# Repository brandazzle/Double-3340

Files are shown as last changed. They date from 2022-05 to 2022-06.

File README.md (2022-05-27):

# Dual 3340 VCO
This module implements two CEM3340/AS3340 VCO ICs, with front panel pulse width and coarse and fine pitch controls, and linear FM, 1V/octave, switchable hard sync (positive/negative/both), and attenuated PWM inputs.
The 1V/octave inputs are connected to each other via switching jacks, so you can control the pitch of the oscillators simultaneously. (Will need to test for pitch slackening with this.) 
\[This functionality can be customized by soldering only one of the 1V/oct input jacks' switch pins, or removed by soldering neither.\]
All outputs are re-centered and normalized to ±5V. A waveshaping circuit based on [Thomas Henry's VCO-1](https://www.birthofasynth.com/Thomas_Henry/Pages/VCO-1.html) provides a sine output. 
The switchable hard sync uses the hard-sync diode circuit from [the original Curtis Electromusic datasheet.](https://www.curtiselectromusic.com/family-law.html)
The module also implements the chip-to-chip soft synchronization described in the original datasheet, wth front-panel switches for each oscillator. Turning on the switch corresponding to each oscillator causes that oscillator to be synchronized by the other, so you can select sync either way, no sync, or mutual sync.

## Construction
<details><summary>View build instructions</summary>

</details>

## Calibration

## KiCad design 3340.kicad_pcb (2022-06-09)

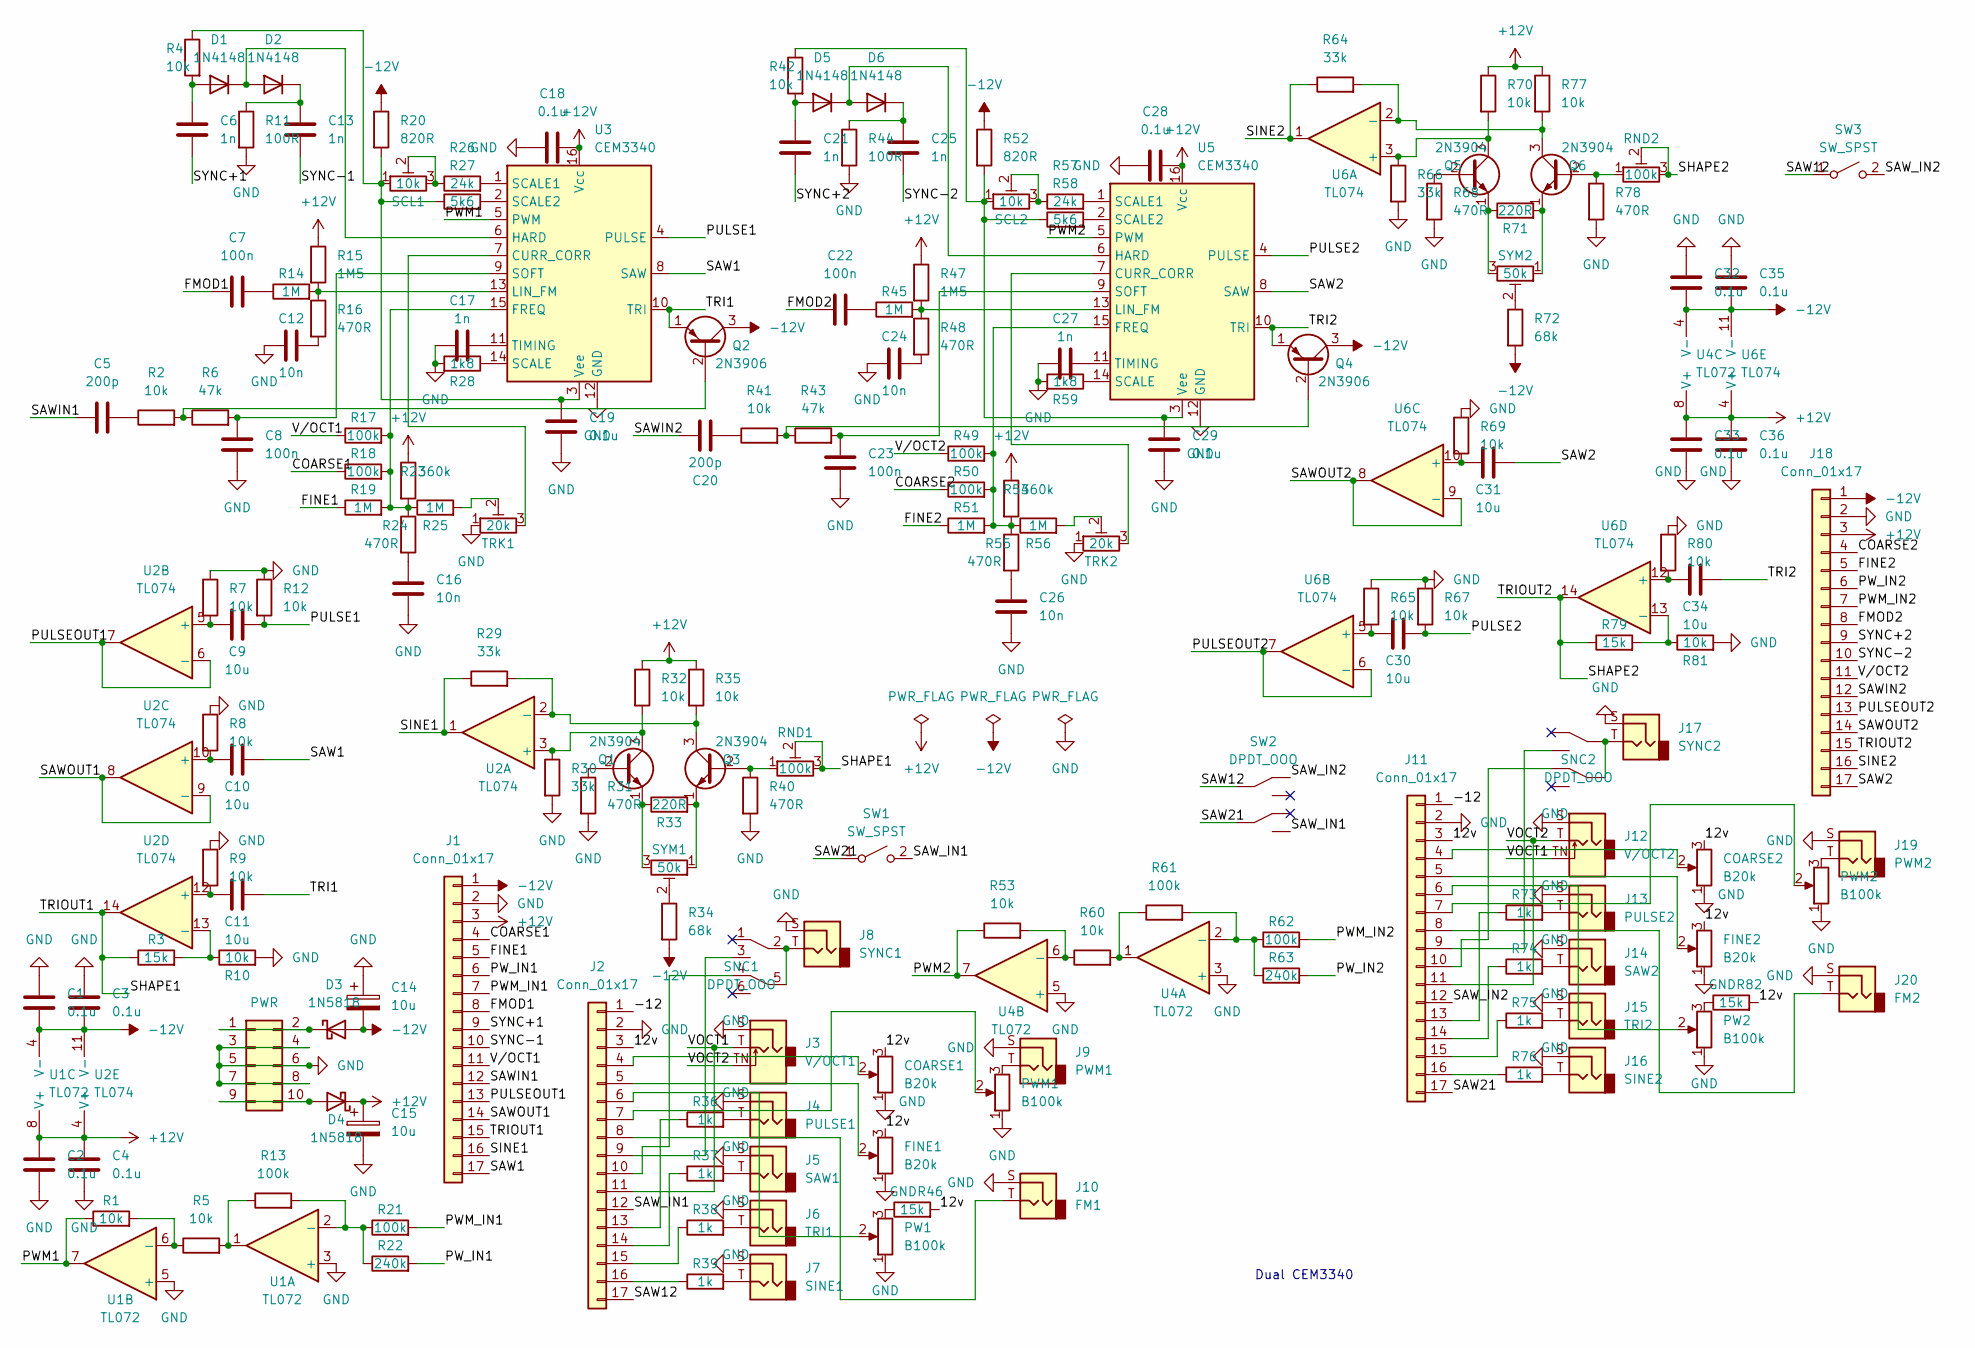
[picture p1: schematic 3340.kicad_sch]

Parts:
C1, C2, C3, C4, C18, C19, C28, C29, C32, C33, C35, C36: 0.1u; C_Disc_D3.8mm_W2.6mm_P2.50mm
C5, C20: 200p; C_Disc_D3.8mm_W2.6mm_P2.50mm
C6, C13, C21, C25: 1n; C_Disc_D3.8mm_W2.6mm_P2.50mm
C7, C8, C22, C23: 100n; C_Disc_D3.8mm_W2.6mm_P2.50mm
C9, C10, C11, C30, C31, C34: 10u; C_Disc_D4.3mm_W1.9mm_P5.00mm
C12, C24, C26: 10n; C_Disc_D3.8mm_W2.6mm_P2.50mm
C14, C15: 10u; CP_Radial_D5.0mm_P2.00mm
C16: 10n; C_Disc_D3.0mm_W1.6mm_P2.50mm
C17, C27: 1n; C_Rect_L7.2mm_W5.5mm_P5.00mm_FKS2_FKP2_MKS2_MKP2
COARSE1, COARSE2: B20k; Potentiometer_Alpha_RD901F-40-00D_Single_Vertical_CircularH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
D1, D2, D5, D6: 1N4148; D_DO-35_SOD27_P7.62mm_Horizontal
D3, D4: 1N5818; D_DO-41_SOD81_P10.16mm_Horizontal
FINE1, FINE2: B20k; Potentiometer_Alpha_RD901F-40-00D_Single_Vertical_CircularH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
J1, J2, J11, J18: Conn_01x17; PinHeader_1x17_P2.54mm_Vertical
J3: V/OCT1; Jack_3.5mm_QingPu_WQP-PJ398SM_Vertical_CircularHoles
J4: PULSE1; Jack_3.5mm_QingPu_WQP-PJ398SM_Vertical_CircularHoles
J5: SAW1; Jack_3.5mm_QingPu_WQP-PJ398SM_Vertical_CircularHoles
J6: TRI1; Jack_3.5mm_QingPu_WQP-PJ398SM_Vertical_CircularHoles
J7: SINE1; Jack_3.5mm_QingPu_WQP-PJ398SM_Vertical_CircularHoles
J8: SYNC1; Jack_3.5mm_QingPu_WQP-PJ398SM_Vertical_CircularHoles
J9: PWM1; Jack_3.5mm_QingPu_WQP-PJ398SM_Vertical_CircularHoles
J10: FM1; Jack_3.5mm_QingPu_WQP-PJ398SM_Vertical_CircularHoles
J12: V/OCT2; Jack_3.5mm_QingPu_WQP-PJ398SM_Vertical_CircularHoles
J13: PULSE2; Jack_3.5mm_QingPu_WQP-PJ398SM_Vertical_CircularHoles
J14: SAW2; Jack_3.5mm_QingPu_WQP-PJ398SM_Vertical_CircularHoles
J15: TRI2; Jack_3.5mm_QingPu_WQP-PJ398SM_Vertical_CircularHoles
J16: SINE2; Jack_3.5mm_QingPu_WQP-PJ398SM_Vertical_CircularHoles
J17: SYNC2; Jack_3.5mm_QingPu_WQP-PJ398SM_Vertical_CircularHoles
J19: PWM2; Jack_3.5mm_QingPu_WQP-PJ398SM_Vertical_CircularHoles
J20: FM2; Jack_3.5mm_QingPu_WQP-PJ398SM_Vertical_CircularHoles
PW1, PW2: B100k; Potentiometer_Alpha_RD901F-40-00D_Single_Vertical_CircularH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
PWM1, PWM2: B100k; Potentiometer_Alpha_RD901F-40-00D_Single_Vertical_CircularH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
PWR1: PWR; IDC-Header_2x05_P2.54mm_Vertical
Q1, Q3, Q5, Q6: 2N3904; TO-92_Inline
Q2, Q4: 2N3906; TO-92_Inline
R1, R2, R4, R5, R7, R8, R9, R10, R12, R32, R35, R41, R42, R53, R60, R65, R67, R69, R70, R77, R80, R81: 10k; R_Axial_DIN0207_L6.3mm_D2.5mm_P10.16mm_Horizontal
R3, R46, R79, R82: 15k; R_Axial_DIN0207_L6.3mm_D2.5mm_P10.16mm_Horizontal
R6, R43: 47k; R_Axial_DIN0207_L6.3mm_D2.5mm_P10.16mm_Horizontal
R11, R44: 100R; R_Axial_DIN0207_L6.3mm_D2.5mm_P10.16mm_Horizontal
R13, R17, R18, R21, R49, R50, R61, R62: 100k; R_Axial_DIN0207_L6.3mm_D2.5mm_P10.16mm_Horizontal
R14, R19, R25, R45, R51, R56: 1M; R_Axial_DIN0207_L6.3mm_D2.5mm_P10.16mm_Horizontal
R15, R47: 1M5; R_Axial_DIN0207_L6.3mm_D2.5mm_P10.16mm_Horizontal
R16, R24, R31, R40, R48, R55, R68, R78: 470R; R_Axial_DIN0207_L6.3mm_D2.5mm_P10.16mm_Horizontal
R20, R52: 820R; R_Axial_DIN0207_L6.3mm_D2.5mm_P10.16mm_Horizontal
R22, R63: 240k; R_Axial_DIN0207_L6.3mm_D2.5mm_P10.16mm_Horizontal
R23, R54: 360k; R_Axial_DIN0207_L6.3mm_D2.5mm_P10.16mm_Horizontal
R26, R57: 24k; R_Axial_DIN0207_L6.3mm_D2.5mm_P10.16mm_Horizontal
R27, R58: 5k6; R_Axial_DIN0207_L6.3mm_D2.5mm_P10.16mm_Horizontal
R28, R59: 1k8; R_Axial_DIN0207_L6.3mm_D2.5mm_P10.16mm_Horizontal
R29, R30, R64, R66: 33k; R_Axial_DIN0207_L6.3mm_D2.5mm_P10.16mm_Horizontal
R33, R71: 220R; R_Axial_DIN0207_L6.3mm_D2.5mm_P10.16mm_Horizontal
R34, R72: 68k; R_Axial_DIN0207_L6.3mm_D2.5mm_P10.16mm_Horizontal
R36, R37, R38, R39, R73, R74, R75, R76: 1k; R_Axial_DIN0207_L6.3mm_D2.5mm_P10.16mm_Horizontal
RND1, RND2: 100k; Potentiometer_Bourns_3296W_Vertical
SCL1, SCL2: 10k; Potentiometer_Bourns_3296W_Vertical
SNC1, SNC2: DPDT_OOO; SW_DPDT_Toggle_Miniature_Lug
SW1, SW3: SW_SPST; SW_SPST_Toggle_Subminiature
SW2: DPDT_OOO; SW_DPDT_Toggle_Miniature_Lug
SYM1, SYM2: 50k; Potentiometer_Bourns_3296W_Vertical
TRK1, TRK2: 20k; Potentiometer_Bourns_3296W_Vertical
U1, U4: TL072; DIP-8_W7.62mm_Socket_LongPads
U2, U6: TL074; DIP-14_W7.62mm_Socket_LongPads
U3, U5: CEM3340; DIP-16_W7.62mm_Socket_LongPads

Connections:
+12V: C2.1, C4.1, C15.1, C18.2, C28.2, C33.1, C36.1, D4.1 (K), J1.3, J18.3, R15.1, R23.1, R32.1, R35.1, R47.1, R54.1, R70.1, R77.1, U1.8 (V+), U2.4 (V+), U3.16 (Vcc), U4.8 (V+), U5.16 (Vcc), U6.4 (V+)
-12V: C1.2, C3.2, C14.2, C32.2, C35.2, D3.2 (A), J1.1, J18.1, Q2.3 (C), Q4.3 (C), R20.1, R34.2, R52.1, R72.2, U1.4 (V-), U2.11 (V-), U4.4 (V-), U6.11 (V-)
/12v: COARSE1.3, COARSE2.3, FINE1.3, FINE2.3, J2.3, J11.3, R46.2, R82.2
/-12: J2.1, J11.1
/COARSE1: J1.4, R18.1
/COARSE2: J18.4, R50.1
/FINE1: J1.5, R19.1
/FINE2: J18.5, R51.1
/FMOD1: C7.1, J1.8
/FMOD2: C22.1, J18.8
/PULSE1: C9.2, R12.2, U3.4 (PULSE)
/PULSE2: C30.2, R67.2, U5.4 (PULSE)
/PULSEOUT1: J1.13, U2.6 (-), U2.7
/PULSEOUT2: J18.13, U6.6 (-), U6.7
/PWM1: R1.1, U1.7, U3.5 (PWM)
/PWM2: R53.1, U4.7, U5.5 (PWM)
/PWM_IN1: J1.7, R21.2
/PWM_IN2: J18.7, R62.2
/PW_IN1: J1.6, R22.2
/PW_IN2: J18.6, R63.2
/SAW1: C10.2, J1.17, U3.8 (SAW)
/SAW2: C31.2, J18.17, U5.8 (SAW)
/SAW12: J2.17, SW2.2, SW3.1 (A)
/SAW21: J11.17, SW1.1 (A), SW2.5
/SAWIN1: C5.1, J1.12
/SAWIN2: C20.1, J18.12
/SAWOUT1: J1.14, U2.8, U2.9 (-)
/SAWOUT2: J18.14, U6.8, U6.9 (-)
/SAW_IN1: J2.12, SW1.2 (B), SW2.6
/SAW_IN2: J11.12, SW2.1, SW3.2 (B)
/SHAPE1: J1.15, R3.1, RND1.2, RND1.3, U2.14
/SHAPE2: J18.15, R79.1, RND2.2, RND2.3, U6.14
/SINE1: J1.16, R29.1, U2.1
/SINE2: J18.16, R64.1, U6.1
/SYNC+1: C6.2, J1.9
/SYNC+2: C21.2, J18.9
/SYNC-1: C13.2, J1.10
/SYNC-2: C25.2, J18.10
/TRI1: C11.2, Q2.1 (E), U3.10 (TRI)
/TRI2: C34.2, Q4.1 (E), U5.10 (TRI)
/VOCT1: J2.11, J3.T, J12.TN
/VOCT2: J3.TN, J11.11, J12.T
/V/OCT1: J1.11, R17.1
/V/OCT2: J18.11, R49.1
GND: C1.1, C2.2, C3.1, C4.2, C8.2, C12.1, C14.1, C15.2, C16.2, C17.1, C18.1, C19.2, C23.2, C24.1, C26.2, C27.1, C28.1, C29.2, C32.1, C33.2, C35.1, C36.2, COARSE1.1, COARSE2.1, FINE1.1, FINE2.1, J1.2, J2.2, J3.S, J4.S, J5.S, J6.S, J7.S, J8.S, J9.S, J10.S, J11.2, J12.S, J13.S, J14.S, J15.S, J16.S, J17.S, J18.2, J19.S, J20.S, PW1.1, PW2.1, PWM1.1, PWM2.1, PWR1.3, PWR1.4, PWR1.5, PWR1.6, PWR1.7, PWR1.8, R7.1, R8.1, R9.1, R10.2, R11.2, R12.1, R28.2, R30.2, R31.2, R40.2, R44.2, R59.2, R65.1, R66.2, R67.1, R68.2, R69.1, R78.2, R80.1, R81.2, TRK1.1, TRK2.1, U1.3 (+), U1.5 (+), U3.12 (GND), U4.3 (+), U4.5 (+), U5.12 (GND)
unnamed: C5.2, R2.1
unnamed: C6.1, D1.2 (A), R4.2
unnamed: C7.2, R14.1
unnamed: C8.1, R6.2, U3.9 (SOFT)
unnamed: C9.1, R7.2, U2.5 (+)
unnamed: C10.1, R8.2, U2.10 (+)
unnamed: C11.1, R9.2, U2.12 (+)
unnamed: C12.2, R16.2
unnamed: C13.1, D2.1 (K), R11.1
unnamed: C16.1, R24.2
unnamed: C17.2, U3.11 (TIMING)
unnamed: C19.1, R4.1, R20.2, R27.1, SCL1.1, U3.3 (Vee)
unnamed: C20.2, R41.1
unnamed: C21.1, D5.2 (A), R42.2
unnamed: C22.2, R45.1
unnamed: C23.1, R43.2, U5.9 (SOFT)
unnamed: C24.2, R48.2
unnamed: C25.1, D6.1 (K), R44.1
unnamed: C26.1, R55.2
unnamed: C27.2, U5.11 (TIMING)
unnamed: C29.1, R42.1, R52.2, R58.1, SCL2.1, U5.3 (Vee)
unnamed: C30.1, R65.2, U6.5 (+)
unnamed: C31.1, R69.2, U6.10 (+)
unnamed: C34.1, R80.2, U6.12 (+)
unnamed: COARSE1.2, J2.4
unnamed: COARSE2.2, J11.4
unnamed: D1.1 (K), D2.2 (A), U3.6 (HARD)
unnamed: D3.1 (K), PWR1.1, PWR1.2
unnamed: D4.2 (A), PWR1.9, PWR1.10
unnamed: D5.1 (K), D6.2 (A), U5.6 (HARD)
unnamed: FINE1.2, J2.5
unnamed: FINE2.2, J11.5
unnamed: J2.6, PW1.2
unnamed: J2.7, PWM1.2
unnamed: J2.9, SNC1.3
unnamed: J2.10, SNC1.4
unnamed: J2.13, R36.1
unnamed: J2.14, R37.1
unnamed: J2.15, R38.1
unnamed: J2.16, R39.1
unnamed: J4.T, R36.2
unnamed: J5.T, R37.2
unnamed: J6.T, R38.2
unnamed: J7.T, R39.2
unnamed: J8.T, SNC1.2, SNC1.5
unnamed: J9.T, PWM1.3
unnamed: J2.8, J10.T
unnamed: J11.6, PW2.2
unnamed: J11.7, PWM2.2
unnamed: J11.8, J20.T
unnamed: J11.9, SNC2.3
unnamed: J11.10, SNC2.4
unnamed: J11.13, R73.1
unnamed: J11.14, R74.1
unnamed: J11.15, R75.1
unnamed: J11.16, R76.1
unnamed: J13.T, R73.2
unnamed: J14.T, R74.2
unnamed: J15.T, R75.2
unnamed: J16.T, R76.2
unnamed: J17.T, SNC2.2, SNC2.5
unnamed: J19.T, PWM2.3
unnamed: PW1.3, R46.1
unnamed: PW2.3, R82.1
unnamed: Q1.1 (E), R33.1, SYM1.3
unnamed: Q1.2 (B), R31.1
unnamed: Q1.3 (C), R30.1, R32.2, U2.3 (+)
unnamed: Q2.2 (B), R2.2, R6.1
unnamed: Q3.1 (E), R33.2, SYM1.1
unnamed: Q3.2 (B), R40.1, RND1.1
unnamed: Q3.3 (C), R29.2, R35.2, U2.2 (-)
unnamed: Q4.2 (B), R41.2, R43.1
unnamed: Q5.1 (E), R71.1, SYM2.3
unnamed: Q5.2 (B), R68.1
unnamed: Q5.3 (C), R66.1, R70.2, U6.3 (+)
unnamed: Q6.1 (E), R71.2, SYM2.1
unnamed: Q6.2 (B), R78.1, RND2.1
unnamed: Q6.3 (C), R64.2, R77.2, U6.2 (-)
unnamed: R1.2, R5.1, U1.6 (-)
unnamed: R3.2, R10.1, U2.13 (-)
unnamed: R5.2, R13.1, U1.1
unnamed: R13.2, R21.1, R22.1, U1.2 (-)
unnamed: R14.2, R15.2, R16.1, U3.13 (LIN_FM)
unnamed: R17.2, R18.2, R19.2, R23.2, R24.1, R25.1, U3.15 (FREQ)
unnamed: R25.2, TRK1.2
unnamed: R26.1, SCL1.2, SCL1.3
unnamed: R26.2, U3.1 (SCALE1)
unnamed: R27.2, U3.2 (SCALE2)
unnamed: R28.1, U3.14 (SCALE)
unnamed: R34.1, SYM1.2
unnamed: R45.2, R47.2, R48.1, U5.13 (LIN_FM)
unnamed: R49.2, R50.2, R51.2, R54.2, R55.1, R56.1, U5.15 (FREQ)
unnamed: R53.2, R60.1, U4.6 (-)
unnamed: R56.2, TRK2.2
unnamed: R57.1, SCL2.2, SCL2.3
unnamed: R57.2, U5.1 (SCALE1)
unnamed: R58.2, U5.2 (SCALE2)
unnamed: R59.1, U5.14 (SCALE)
unnamed: R60.2, R61.1, U4.1
unnamed: R61.2, R62.1, R63.1, U4.2 (-)
unnamed: R72.1, SYM2.2
unnamed: R79.2, R81.1, U6.13 (-)
unnamed: TRK1.3, U3.7 (CURR_CORR)
unnamed: TRK2.3, U5.7 (CURR_CORR)

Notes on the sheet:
Dual CEM3340

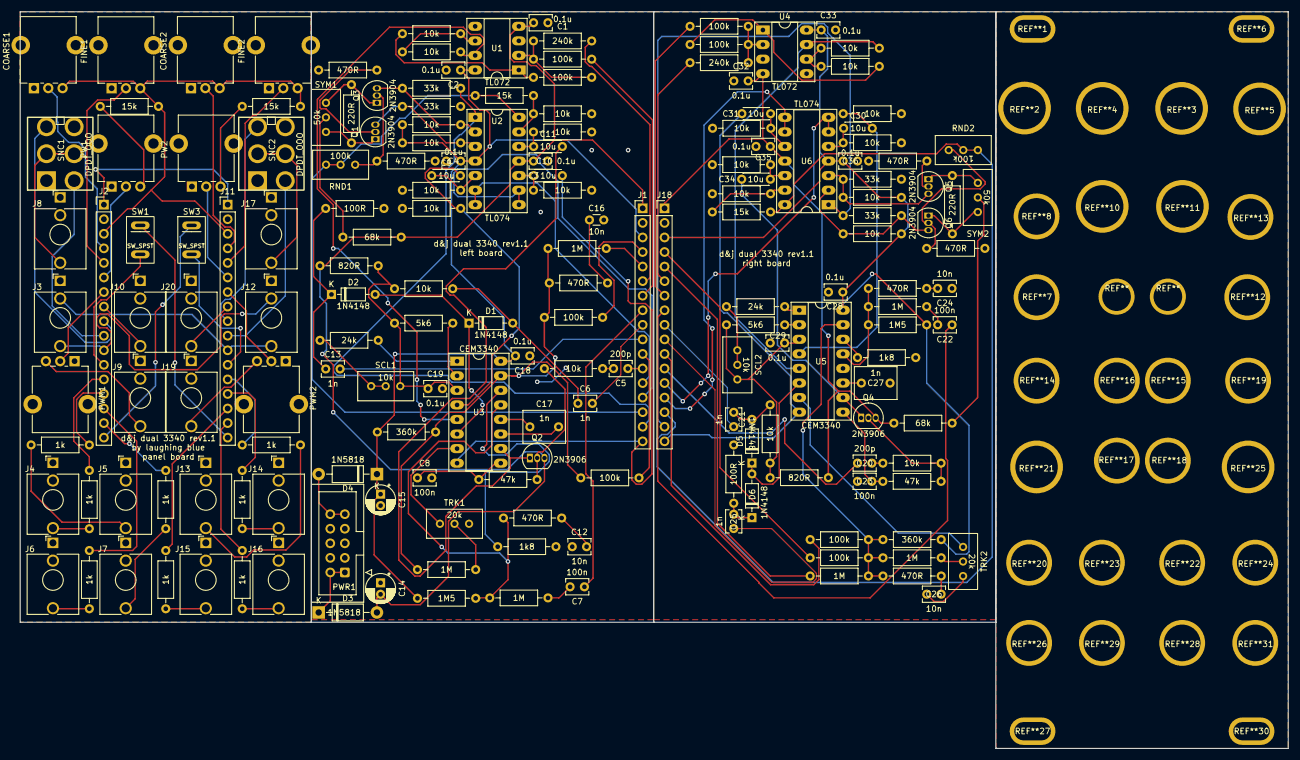
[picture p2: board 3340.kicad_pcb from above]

Board: 2 copper layers, 221.2 x 128.5 mm, 177 parts (0 on the bottom side), 149 nets.

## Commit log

2022-05-10 Fix power routing
    [3340.kicad_pcb, 3340.kicad_sch]
2022-05-10 Update pin header footprints
    [3340.kicad_sch]
2022-05-10 Fix synch switches in schematic
    [3340.kicad_pcb, 3340.kicad_sch]
2022-05-10 Fix sync switches on board
    [3340.kicad_pcb]
2022-05-10 Add value labels to potentiometers
    [3340.kicad_pcb, 3340.kicad_sch]
2022-05-10 Fix electrolytic footprints
    [3340.kicad_pcb, 3340.kicad_sch]
2022-05-10 Start backboard 1
    [3340.kicad_pcb]
2022-05-10 Use autoplace from here
    [3340.kicad_pcb]
2022-05-10 Fix PWM2 connection
    [3340.kicad_pcb, 3340.kicad_sch]
2022-05-10 Finish backboard 1
    [3340.kicad_pcb]
2022-05-10 Start backboard 2
    [3340.kicad_pcb]
2022-05-10 Finish backboard 2
    [3340.kicad_pcb]
2022-05-10 Fix grid alignment
    [3340.kicad_pcb]
2022-05-10 Add spacing measurements
    [3340.kicad_pcb]
2022-05-11 Further comments
    [3340.kicad_pcb]
2022-05-11 Fix IC labels
    [3340.kicad_pcb]
2022-05-11 Exclude corner mounts from BOM
    [3340.kicad_pcb]
2022-05-11 Add panel positions
    [3340.kicad_pcb]
2022-05-11 Adjust all potentiometers
    [3340.kicad_pcb]
2022-05-11 Fix various errors
    [3340.kicad_pcb]
2022-05-11 Adjust panel placements
    [3340.kicad_pcb]
2022-05-11 Add panel holes
    [3340.kicad_pcb]
2022-05-11 Fill testing
    [3340.kicad_pcb]
2022-05-12 Fix switch footprints
    [3340.kicad_pcb]
2022-05-17 Add independent sync switches
    [3340.kicad_sch]
2022-05-23 Update footprints
    [3340.kicad_pcb, 3340.kicad_sch]
2022-05-23 Wire new switches
    [3340.kicad_pcb]
2022-05-24 Mark switch holes
    [3340.kicad_pcb, 3340.kicad_sch]
2022-05-24 Add some panel hole nets
    [3340.kicad_pcb]
2022-05-24 Ground panel holes
    [3340.kicad_pcb]
2022-05-27 Add new switch mounting holes
    [3340.kicad_pcb]
2022-05-27 Fix switch footprint flat line placement
2022-05-27 Add panel ground planes
    [3340.kicad_pcb]
2022-05-28 Add measurements for misalignment fixing
    [3340.kicad_pcb]
2022-06-09 Add all panel correction measurements
    [3340.kicad_pcb]
